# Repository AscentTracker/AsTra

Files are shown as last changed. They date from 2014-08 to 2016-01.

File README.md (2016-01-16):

AsTra
=====

Ascent Tracker "AsTra" is an Arduino-based altitude data logger for
(indoor)climbing.

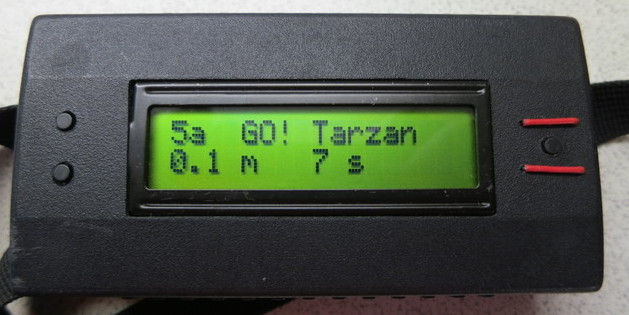
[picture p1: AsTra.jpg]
AsTra picture
 

AsTra is a smallish (12x6x2.5 cm, 200 g) wearable device to record
altitude (based on barometric pressure) four times a second to an
SD card. For convenience also time, name of the climber and grade of
the route are selectable and stored with every ascent. The data are
processed with a Perl program to yield daily ascent curves (with
[dygraphs](http://dygraphs.com/)) for every climber.

The [demo graph for Tarzan](http://www.helsinki.fi/~syrjanen/AsTra/Tarzan/2014-05-27.html)
displays each ascent as a curve, height versus time. You can select
which ascents are visible, zoom in with mouse etc. Monthy and yearly
[statistics](http://www.helsinki.fi/~syrjanen/AsTra/Tarzan/Stats.html) are calculated for every climber.

Check these directories for more information on design, inspiration and
building the hardware and software:

- [hw](hw): AsTra hardware and Arduino software
- [tools](tools): Linux software and tools for graphing AsTra data

Pictures, demo video and some notes on building AsTra can be found
in [AsTra image library](http://pars.kuvat.fi/kuvat/AsTra/?pw=AsTra)

&copy; Seppo Syrjänen 2014, 2016

*Contact: ascend dot tracker at gmail dot com*

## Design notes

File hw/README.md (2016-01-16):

AsTra
=====

I wanted log my indoor climbing ascents with some automatic tracking
device to map altitude versus time. Measuring altitude could be done
actively with ultrasound or optical ranging but modern barometric
pressure sensors could do that passively and without calibration,
especially when only relative altitudes are required.

I was amazed by the
[videos](http://www.varesano.net/blog/fabio/ms5611-01ba-arduino-library-first-developments-results)
by Fabio Varesano about barometric pressure sensor MS5611-01BA01. A
resolution of a 50 cm would have been enough for logging climbing
routes but sensitivity of just 10 centimeters was more than I could
have hoped for. Individual altitude readouts from the sensor are noisy,
but averaging and filtering saves the day.

AsTra is also inspired by these projecs and tutorials:

* [FreeIMU](http://www.varesano.net/projects/hardware/FreeIMU) has the current library for MS5611
* [Altduino](http://www.altduino.de/) altitude logger for model rockets
* [openxvario](https://code.google.com/p/openxvario/) for RC planes, especially for **Kalman filtering** code
* [Arduino DIY SD Card Logging Shield](http://www.instructables.com/id/Arduino-DIY-SD-Card-Logging-Shield/) for cheap LC Studio SD card breakout
* [SD Card info in arduino-info](http://arduino-info.wikispaces.com/SD-Cards)
* [Why not to use 9 V batteries](http://cybergibbons.com/uncategorized/arduino-misconceptions-6-a-9v-battery-is-a-good-power-source/)
* [Resistor ladder](http://tronixstuff.com/2011/01/11/tutorial-using-analog-input-for-multiple-buttons/) to read multiple buttons via one analog input
* [Analog debounce](https://github.com/MatCat/AnalogDebounce) library to simpilify reading the buttons
* [Optimizing RAM usage](http://learn.adafruit.com/memories-of-an-arduino/optimizing-sram)

Parts list
----------

- Arduino Mini Pro 5V
- SCG MS5611 breakout
- Sparkfun Logic Level Converter
- Adafruit RTC module
- Sparkfun NCP1402-5V Step-Up Breakout
- 1117T-3.3V regulator + capacitors
- Sparkfun MicroSD breakout
- 2 x 16 LCD display
- buttons, resistors
- project box

Cost ~ 100 €, build time ~ 100 hours (includes lots of hw and sw prototyping & documentation) ;-)

Building the hardware
---------------------

I got my MS5611 breakout from
[CSG](http://www.csgshop.com/category.php?id_category=10). It arrived
with no documentation so I just had to guess with help of a similar
product by
[Drotek](http://www.drotek.fr/shop/en/home/44-ms5611-pressure-barometric-board.html)
on how to enable I2C mode and select the device address by soldering
**two** jumper pads.

Cheap SD card module from LC Studio was too big for my enclosure so I had to
use a MicroSD version from Sparkfun. That had the nice bonus of
eliminating the need for a 4050 level converter.

[Fritzing](http://fritzing.org/home/) [breadboard
view](AsTra-V0.44_bb.png) was a nice way
to plan and document(!) wirings on a proto board. Export to a PNG and
flip it over to give view from the solder side. Fritzing [schematic
view](AsTra-V0.44_schem.png) was
used in documenting the actual circuit design. Download
[AsTra-V0.44.fzz](AsTra-V0.44.fzz) for
complete Fritzing project.

I used [Inkscape](http://www.inkscape.org/en/) to draw "parts" for the
connectors and to rescale some (inch-measured?) Sparkfun
[parts](https://github.com/adafruit/Fritzing-Library/blob/master/parts/2.2%20TFT%20with%20MicroSD%20Breakout.fzpz).

I happened to select a box that was just big enough for all stuff
needed. My hardest build this far, using only hand tools.

Software 
--------

Version: [AsTra_V1.06](AsTra_V1_06.ino)

Program (event) logic is implemented as a Finite State Machine (FSM, see
graph [AsTra-FSM1-1-1.png](AsTra-FSM1-1-1.png)).

Sensor readings are cleaned with Kalman digital filtering. Also a
32-slot moving average is calculated for debugging. See [DATA.md](DATA.md) for
all fields. 

Starting and stopping the ascent tracking automatically (as indicated
in FSM and AUTOSTART macro in code) was more trouble than it was
worth. One button push before and two after ascent is mostly not too
much to remember. 

Arduino memory size limits are always a problem: some recent change in
Arduino IDE (Linux versions) bloated the binary over maximun size so I
had to disable all serial debugging output. Maybe I need a debugging
version with partial functionality?

MS5611 library returning NULL for a float on invalid data got me in a
big way. Note that
[MS561101BA_altitude.pde](https://github.com/PaulStoffregen/FreeIMU/blob/master/libraries/MS561101BA/examples/MS561101BA_altitude/MS561101BA_altitude.pde)
does NOT check for NULL return values as
[MS561101BA_simple.pde](https://github.com/PaulStoffregen/FreeIMU/blob/master/libraries/MS561101BA/examples/MS561101BA_simple/MS561101BA_simple.pde)
does. Those NULL values messed up the Kalman filtering code and
shortcircuited simple float calculation (foo - NULL = 0.0). Note to
self: always check return values and read interface descriptions.

Climbing grades are according to French (indoor) system: ?, 4, 4+, 5a,
5a+, 5b, 5b+, 5c, 5c+, 6a, 6a+,... Modify gradenum2name() to suit your
needs.

Sensor initialization and setup code is inside loop() because
replicating them in setup() would bloat the binary. Sorry for the
inconvenience.

Static variables are used in openLog() to eliminate the need of scanning
the SD card for the next availabe filename while the power is still on.

Device is powered off after 10 minutes on inactivity. This drops the
current consumption from 21 mA to 7 mA so this is mostly an
excercise in power saving techniques.

See [USER-GUIDE.md](USER-GUIDE.md) for how the device is actually used.

Enhancements and alternatives
-----------------------------

Altitude readings tend to drift even when stationary. Longer (in time)
routes tend to end couple of meters higher than started. Possible
causes include temperature at different altitudes, wind and changes in
air conditioning affecting the local barometric pressure. CSV data
have altitude values calculated based on starting and current
temperature (see [DATA.md](DATA.md)) but I have not managed to find any
explanation for the drift.

One might use a second stationary unit for reference like in
differential GPS :-) On the other hand, the device is accurate enough
for my current needs where a resolution of 0.5 meters would suffice.

Alternative sw/hw designs:

* use TinyFAT as SD library (partition card for smaller capacity)
* replace AnalogDebounce with a smaller implementation
* replace rest of printfs with smaller code
* use I2C EEPROM chip for storage, build data download functionality
* add a BlueTooth connection to PC/smartphone app
* use LiPo as power source
* PCB

**See more notes on building in [image captions](http://pars.kuvat.fi/kuvat/AsTra/)**

Be sure to check [Climbit](http://www.instructables.com/id/Climbit/)
for a more modern choice of components. I started AsTra when e.g. Trinket
and OLED displays were not readily available.

&copy; Seppo Syrjänen 2014,2016

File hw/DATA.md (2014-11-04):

AsTra Data
----------

Each ascent is recorded to a file on SD card (poweroff before
removing card). Filenames are in format of YYMMDDAA.CSV
where YY is year (with two digits, sorry Y2K), MM is month, DD is day
and AA goes from AA to ZZ (so there is room for 625 ascents for each day).

First line has metadata in JSON-format, rest of the lines have
altitude etc data for the ascent in CSV format.
Line "#FAILED" indicates an ascent that has been marked as failed by the Set-button.

AsTra does not record location information. Location is added to
JSON metadata with _setloc_ utility. It can also be specified on command line
to _adastra_.

CSV fields are as follows (mostly used for debugging):

- milliseconds from start
- raw altitude from the sensor (based on starting temperature), in meters
- moving average of altitude
- kalman filtered altitude: only this is used by adastra
- power supply voltage
- altitude based on current temperature
- current temperature, degrees of C

AsTra V 1.* hardware stores four (4) records every second, _adastra_
uses every other of them.

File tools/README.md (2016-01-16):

AsTra Data Reporting
=================

You can plot AsTra CSV files in any way you want, see [DATA.md](DATA.md) for
field information. These Linux flavored
tools produce HTML+CSV files for [dygraphs](http://dygraphs.com/) visualization library and
Apache flavored www server. Porting to Windows and IOS would not be
too hard.

Software needed:

- rsync to smartly move files, use cp if not available
- Perl

*Tools provided*:

- _getnew_: shell program to fetch new files from SD card, runs _adastra_
- _adastra_: Perl program to process CSV files to logs and WWW reports
- _stats_: Perl program to calculate montly and yearly statistics for every climber
- _publish_: shell program for publishing the results, runs stats first
- _setloc_: Perl program to set JSON location field in CSV files

Install
-------

* edit mount point to _getnew_
* edit WWW charset to _adastra_
* edit publish location to _publish_ (optional)
* chmod a+x getnew adastra publish setloc

Quick usage
-----------

* insert SD card
* ./getnew Location (automatically fetches new files and runs adastra with them)
* ./publish (if you want to publish them to a www server)

You can view the reports with a modern browser in directory [www](www).

You can set location info to CSV files like this

 ./setloc -loc Location data/140606*.CSV

and make reports from those files

 ./adastra -v data/140606*.CSV

You can override location with adastra option -loc

&copy; Seppo Syrjänen 2014,2016

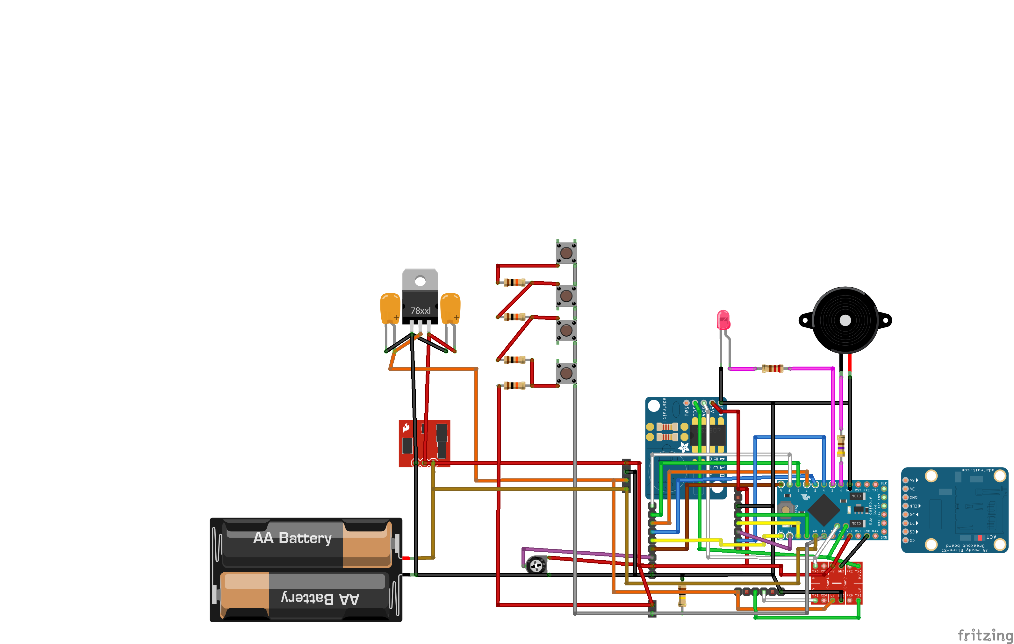
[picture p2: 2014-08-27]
hw/AsTra-V0.44_bb.png

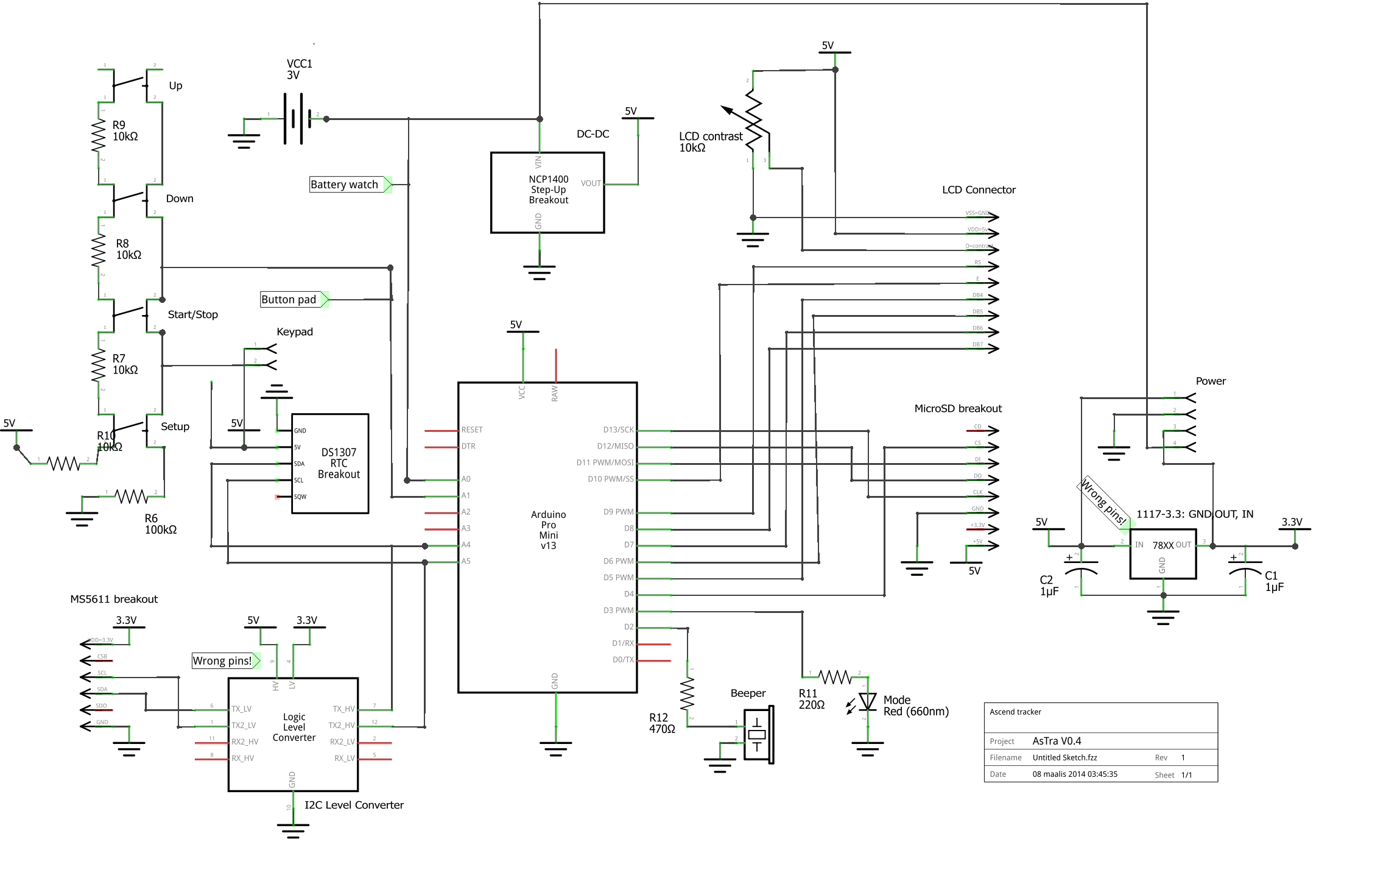
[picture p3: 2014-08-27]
hw/AsTra-V0.44_schem.png

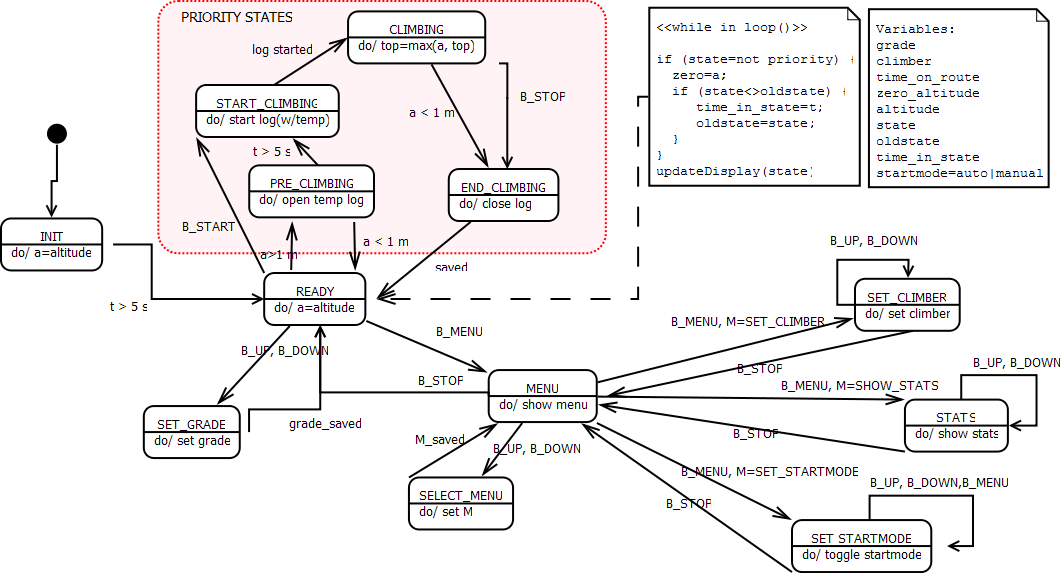
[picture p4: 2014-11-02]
hw/AsTra-FSM1-1-1.png

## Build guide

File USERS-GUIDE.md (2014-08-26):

AsTra Users Guide
=================

Basics
------

- Turn on with power switch, wait 10 seconds for startup/calibration
- Silent mode (no beeps): press any button at poweron 
 or set "b 0" in settings.txt on SD card
- Select grade with Up/Down buttons (?,4,4+,5a,5a+,...9c+)
- Select climber with Set-button (on left edge next to power switch)
- Start climbing with Go-button: clock starts ticking, three beeps
played and GO! displayed
- End climbing with Go-button (finished) or Set-button (failed to
 finish). Totals (altitude and seconds) are displayed until Go is pushed.
- Auto poweroff after 10 minutes of idle (set "i 0" in settings.txt to disable)

Display
-------

The two row LCD displays the following information.

At Power on:
 AsTra version information and battery voltage.

Idle: 

 Left | Middle | Right
 ---- | -------| -----
 Route grade | Alt zero level (blinking square) | Climber name
 Altitude| | Time
 
Climbing:

 Left | Middle | Right
 ---- | -------| -----
 Route grade | GO! | Climber name
 Altitude | |  Elapsed time
 
Stop:

 Left | Middle | Right
 ---- | -------| -----
 Route grade | END | Climber name
 Max altitude | | Time to max alt

Data
----

Each ascent is recorded to a file on SD card (poweroff before
removing card). Filenames are in format of 

 YYMMDDab.CSV

where YY is year (with two digits, sorry Y2K), MM is month, DD is day
and ab goes from AA to ZZ (there is room for 625 ascents for each day).

First line has metadata in JSON-format, rest of the lines have
altitude etc data for the ascent in CSV format.
Line "#FAILED" indicates an ascent that has been marked as failed by the Set-button.

AsTra does not record location information. Location is added to
JSON metadata with _setloc_ utility. It can be specified on command line
also to _adastra_.

CSV fields are as follows (mostly used for debugging):

- milliseconds from start
- raw altitude from the sensor (based on starting temperature)
- moving average of altitude
- kalman filtered altitude: only this is used by adastra
- power supply voltage
- altitude based on current temperature
- current temperature

AsTra stores four (4) records every second, _adastra_ displays two of
them.

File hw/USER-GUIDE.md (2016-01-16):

AsTra Users Guide V1.06
=======================

Basics
------

- Turn on with power switch, wait 10 seconds for startup/calibration
- Silent mode (no beeps): press any button at poweron 
 or set "b 0" in settings.txt on SD card
- Select grade with Up/Down buttons (?,4,4+,5a,5a+,...9c+)
- Select climber with Set-button (on left edge next to power switch)
  Running statistis (since poweron) for each climber are displayed.
  Press Go to select climber.
- Start climbing with Go-button: clock starts ticking, three beeps
  played and GO! displayed
- End climbing with Go-button (finished) or Set-button (failed to
  finish). Totals (altitude and seconds) and END are displayed until Go is pushed.
- Auto poweroff after 10 minutes of idle (set "i 0" in settings.txt to disable)
- If battery voltage drops below 2.0 V a warning and voltage reading are
  displayded until power is recycled. Exact safe lowest voltage level
  is unknown.
- set "d 1" in settings.txt to enable Daylight Savings Time (no need
  to adjust RTC)

Display
-------

The two row LCD displays the following information.

**At Power on:**
 AsTra version information and battery voltage.

**Idle:** 

 Left | Middle | Right
 ---- | -------| -----
 Route grade | Alt zero level (blinking square) | Climber name
 Altitude| | Time
 
**Climbing:**

 Left | Middle | Right
 ---- | -------| -----
 Route grade | GO! | Climber name
 Altitude | |  Elapsed time
 
**Select climber:**

 Left | Middle | Right
 ---- | -------| -----
 Total ascents | | Climber name
 Total meters | | Total time

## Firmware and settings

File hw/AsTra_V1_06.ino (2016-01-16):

/*

Arduino Mini Pro 5V ATmega328

FIX
-i 10 setting for idle poweroff
-b 0 setting for mute

22.11.2015
 -d 1 to set daylight savings time

23.5.2015
 -stats
 -shorten beeps and init delay

26.1.2015
 -fixed: idle poweroff entered when ascent longer than 10 minutes was marked as failed (introduced B_NONE) 

27.10.2014

+9c+ grade?

20.8.2014

 TODO:
 -smaller analogDebounce
 -smaller getSettings
 -use tinyFAT, writeLn -> write (no long string buffer)?

Version history:

0.24
 -log current temperature and temp_altitude based on it (long ascents tend to end higher than they started; why?) 

0.23
 -auto shutoff after idle

1.01
 -voltage display at startup, grade 4+

1.05
 -show daily stats at climber selection

*/


// Poweroff if idle after 10 minutes
#include <avr/sleep.h>


#include <ctype.h>
#include <SD.h>

#define SHOWFREEMEM 0
#define HWLCD 1
#define HWRTC 1
#define TEMPDEBUG 0

byte HWSD=1;

#define buttonPin A1
#define piezoPin 2
#define chipSelect 4


#include <Wire.h>
#include <MS561101BA.h>
#if HWRTC
#include <RTClib.h>
#endif

#if HWLCD
#include <LiquidCrystal.h>

// initialize the library with the numbers of the interface pins
// LiquidCrystal LCD(RS, Enable, D4, D5, D6, D7)

LiquidCrystal LCD(9, 10, 5, 6, 7, 8);

#endif

#include <AnalogDebounce.h>
  AnalogDebounce Buttons(buttonPin,ButtonPush);  // Analog Input 0, 

#define B_UP 2
#define B_DOWN 3
#define B_START 1
#define B_MENU 4
#define B_NONE 5


#define S_IDLE 1
#define S_PRECLIMBING 2
#define S_CLIMBING 3
#define S_POSTCLIMBING 4
#define S_SHOW 5
#define S_SELECTCLIMBER 6


// ?,4,4+,5a,5a+,...9c+
#define MAXGRADE 32

RTC_DS1307 RTC; // define the Real Time Clock object
DateTime now;


#define MOVAVG_SIZE 32

MS561101BA baro = MS561101BA();

float movavg_buff[MOVAVG_SIZE];
int movavg_i=0;

const float sea_press = 1013.25;
float press, temperature;

// Timestamps for time and date
char stime[9]; // add space for string terminators! 
char sdate[11];


// the logging file
File logfile;


// Filename template
char filename[] = "YYMMDD00.CSV";


float avg_altitude;
float raw_altitude;
float zero;
float lastaltitude;
// float rate;
float kalman_altitude=0.0;
float maxalt=0.0;

uint32_t mnow=0;
uint32_t lastprint=0;
uint32_t lastsync=0;
uint32_t starttime=0;
uint32_t endtime=0;
uint32_t start_stop_autotimer=0;
uint32_t zerotime=0;
uint32_t INTERVAL=250;
// auto poweroff after 10 minutes with no button activity
uint32_t lastbuttontime=0;
#define IDLEPOWEROFF 600000 

char str[6];
byte grade=3; // start with 5a
byte beep=2; // 0=silent, 1=startup & error, 2=all
byte mute=0; // set to 1 if button pressed at boot
byte failed=0; // failed to ascend to the top
byte autostart=1; // enable autostart/stop
byte button=0;
byte initloop=0;
byte state=S_IDLE;
byte displayvolts=0;
byte dst=0;

byte numclimbers=0;
char **climbername=NULL;
byte climber=0;

struct stat_r
{
  byte ascents;
  float meters;
  int seconds;
};

typedef struct stat_r Stat;

Stat *stats=NULL;


/***************************************************************************************/
/* sensitivity / data filtering / n filter parameters                             */
/* The Kalman Filter is being used to remove noise from the MS5611 sensor data. It can */
/* be adjusted by changing the value Q (process Noise) and R (Sensor Noise).           */
/* Best pactise is to only change R, as both parametrers influence each other.         */
/* (less Q requires more R to compensate and vica versa)                               */
/***************************************************************************************/
#define KALMAN_Q 0.05 // 0.05 do not tamper with this value unless you are looking for adventure ;-)
#define KALMAN_R 80  // default:300   change this value if you want to adjust the default sensitivity!
                      // this will only be used if PIN_PPM is NOT defined
                      //  50 = fast but lot of errors (good for sensor testing...but quite a lot of noise)
                      // 300 = medium speed and less false indications (nice medium setting with 
                      //       a silence window (indoor)of -0.2 to +0.2)
                      // 1000 = conservative setting ;-)
                      // 500 = still useable maybe for a slow flyer?
                      // 1000 and q=0.001 is it moving at all?? in stable airpressure you can measure 
                      //      the height of your furniture with this setting. but do not use it for flying ;-)
                      // .. everything inbetween in relation to these values.

float kalman_q= KALMAN_Q; //process noise covariance
float kalman_r= KALMAN_R; //measurement noise covariance

// Kalman filter variables/parameters
float p=100; //estimation error covariance
float k=0; //kalman gain

// <<<<<<<<<<<<<<<<<<<<<<<<<<<<<<<<<<<<<<<<<<<<<<<

#define S(a) Serial.print(a);
// As of IDE 1.1 no more code space for serial debugging, pity
#define S(a) ;
#define L(a) S(a); logfile.print(a);


#include <avr/pgmspace.h>

// http://forum.arduino.cc/index.php?topic=110307.0

#define FS(x) (__FlashStringHelper*)(x)
#define pm PROGMEM

const char MyName[]        pm ={"AsTra V: "};
const char Version[]       pm ={"1.06"};
const char Battery[]       pm ={"Battery: "};
const char Spaces3[]       pm ={"   "};
const char Spaces4[]       pm ={"    "};
const char SpaceMSpace[]   pm ={" m "};
const char SpaceS[]        pm ={" s"};
const char sError[]        pm ={"Error: "};
const char mallocFailed[]  pm ={"malloc failed"};
const char autoPoweroff[]  pm ={"Idle -> Poweroff"};

// LCD positions Row 1 and 2, Left, Middle and Right columns
#define LCD_R1L 0,0
#define LCD_R1M 4,0
#define LCD_R1R 8,0
#define LCD_R2L 0,1
#define LCD_R2R 8,1

#define FR1 4000
#define BATTERYWARN 2.0 // still to be verified

float supplyvoltage=0.0;

void getVoltage () {        
   supplyvoltage = analogRead(A0);
   delay(10);
   supplyvoltage = analogRead(A0)*(5.0 / 1023);
}


// -------------------------------------------

/*

void statdump(void) {

    Serial.println(stats[climber].ascents);
    Serial.println(stats[climber].meters);
    Serial.println(stats[climber].seconds);
    
}
*/

// -------------------------------------------

void setup() {
  Serial.begin(9600);

  // mute if a button pressed while boot
  if (analogRead(buttonPin)>10) {
    mute=1;
    beep=0;    
  };

  pinMode(piezoPin,OUTPUT);

  // say hello
  buzz(piezoPin, 200, 100, 0);
    
 
  // Initialize the SD card  
  if (HWSD) {
    if (!SD.begin(chipSelect)) {
      HWSD=0;
    } else {
      getSettings();
    };
  };

  if (mute) beep=0;

  // No climbers in settings file, let Tarzan loose!
  if (numclimbers==0) {
    numclimbers=1;
    climbername = (char **)malloc (sizeof (char *) * numclimbers);
    if (!climbername) {
      error(mallocFailed);
    }
    climbername[0]=strdup("Tarzan");  
  }; 
  
  // Start with first climber  
  climber=0;  

  // Initialize statistics array
  stats = (Stat *)malloc (sizeof (Stat) * numclimbers);
  if (!stats) {
      error(mallocFailed);
  }

  for (byte i=0; i<numclimbers; i++) {
    stats[i].ascents=0;
    stats[i].meters=0.0;
    stats[i].seconds=0;
  };  

  // get power supply voltage
  getVoltage();

#if HWLCD
  // set up the LCD's number of columns and rows: 
  LCD.begin(16, 2);
  
  // Print a message to the LCD.  
  LCD.setCursor(LCD_R1L);
  LCD.print(FS(MyName));
  // LCD.setCursor(LCD_R1R);
  // LCD.print(F(" "));
  LCD.print(FS(Version));
  if (dst>0) { LCD.print(F(" *"));};
  // LCD.setCursor(LCD_R2R);
  // LCD.print(F(__TIME__));
  LCD.setCursor(LCD_R2L);
  LCD.print(FS(Battery));
  LCD.print(supplyvoltage);
  LCD.print(F(" V "));
#endif

  // Connect to RTC
  Wire.begin();
  
  if (!RTC.begin()) {
    error("RTC");
  }
 
  // Init MS5611 barometric sensor
  baro.init(MS561101BA_ADDR_CSB_LOW); 
  delay(100);
 
} // end of setup


float temp_altitude;
float temp0;

// =====================================================================

void loop() {

  // check buttons first for best responsiveness
  Buttons.loopCheck();    

  // Must check for invalid values (NULL)    
  temperature=NULL; 
  while(temperature == NULL) {
    temperature = baro.getTemperature(MS561101BA_OSR_4096);
    // delay(20);
  }
  
  press=NULL;
  while (press == NULL) {
    press = baro.getPressure(MS561101BA_OSR_4096);
    // delay(20);
  };
  
  raw_altitude=getAltitude(press, temp0);

  // Update moving average
  pushAvg(press);
  press = getAvg(movavg_buff, MOVAVG_SIZE);
  avg_altitude=getAltitude(press, temp0);
  temp_altitude=getAltitude(press, temperature);
    
  // Update the prediction value
  p = p + kalman_q;

  // Update based on measurement
  k = p / (p + kalman_r);
  kalman_altitude = kalman_altitude + k * (raw_altitude - kalman_altitude);
  p = (1 - k) * p;

  // Get power supply voltage
  getVoltage();

// ============================================
 // Sensor init & avg buffer fillup delay 
// ============================================
    
 if (initloop < MOVAVG_SIZE) {
   temp0=temperature;
   initloop++;
   if (button) {
    mute=1;
    beep=0;
   }
   /* 
   LCD.setCursor(LCD_R2L);
   LCD.print(FS(Battery));
   LCD.print(supplyvoltage);
   LCD.print(F(" V "));
   */
   // LCD.write(255);
   delay(40);
   return;
 } else if (initloop == MOVAVG_SIZE) { // end of init looping
   initloop++;
    
#if HWLCD
    LCD.clear();
    LCD.setCursor(LCD_R1L);
    LCD.print(gradenum2name(grade,str));
    LCD.setCursor(LCD_R1R);
    LCD.print(climbername[climber]);
#endif

   return;
 };


    // millis() now  
    mnow=millis();

    // Fetch the time
    now = RTC.now();

    // Timestamps, lazy DST handling
    sprintf(stime, "%02d:%02d:%02d", now.hour()-dst, now.minute(), now.second());
    sprintf(sdate, "%d-%02d-%02d",   now.year(), now.month(),  now.day());
 
// ============================================
//   BUTTONS
// ============================================

 switch (button) {  
   case B_START:
     buzz(piezoPin, FR1, 100, 100);
     switch (state) {
       case S_IDLE:     setZero(); state=S_PRECLIMBING; break;
       case S_CLIMBING: state=S_POSTCLIMBING; break;
       case S_SHOW:     setZero(); state=S_IDLE; break;
       case S_SELECTCLIMBER:    setZero(); state=S_IDLE; 
#if HWLCD
            LCD.setCursor(LCD_R1L);
            LCD.print(gradenum2name(grade,str));
            LCD.print(FS(Spaces4));
#endif         
       break;
     };
     break;
   case B_MENU: // mark ascent aborted
     switch (state) {
       case S_CLIMBING: failed=true; button=B_NONE; state=S_POSTCLIMBING; break;
       case S_IDLE: button=B_NONE; state=S_SELECTCLIMBER; break;
       case S_SELECTCLIMBER:
             button=B_NONE;
             climber++;
             if (climber>=numclimbers) climber=0;
#if HWLCD
            LCD.setCursor(LCD_R1R);
            LCD.print(climbername[climber]);
            LCD.print(FS(Spaces4));
#endif         
            break;
     };
 };
 
if (state==S_IDLE) {
 switch (button) {     
   case B_UP:
     if (grade<MAXGRADE) grade++;
#if HWLCD
    LCD.setCursor(LCD_R1L);
    LCD.print(gradenum2name(grade,str));
    LCD.print(FS(Spaces4));
#endif    
     break;

   case B_DOWN:
     if (grade>0) grade--;
#if HWLCD
    LCD.setCursor(LCD_R1L);
    LCD.print(gradenum2name(grade,str));
    LCD.print(FS(Spaces4));
#endif    
     break;

/*
   case B_MENU:
     climber++;
     if (climber>=numclimbers) climber=0;
#if HWLCD
    LCD.setCursor(LCD_R1R);
    LCD.print(climbername[climber]);
    LCD.print(FS(Spaces4));
#endif         
     break;
*/ 

 }; // end switch button
}; 

// -----------------------------------------------

switch (state) {
  case S_IDLE:
  
#if AUTOSTART  
    // start when above X meters for y seconds
    if (kalman_altitude-zero > 0.7) {
      if (start_stop_autotimer==0) {
        start_stop_autotimer=mnow;
      } else if (mnow-start_stop_autotimer > 2000) {
        // if (autostart) state=S_PRECLIMBING;
      };
    } else {
      start_stop_autotimer=0;
    };
#endif

   // set zero level when idle and one of these:
   //  -some button is pressed
   //  -10 seconds after boot
   //  -10 seconds after last re-set when after init and not waiting to climb over autostart level
    // if (((start_stop_autotimer==0) && (mnow > 10000)) && (button || (mnow < 10000) || (mnow-zerotime>10000))) {
    if ((button || (mnow < 5000) || 
          ((mnow > 5000)  && (mnow-zerotime>30000) && (start_stop_autotimer==0)))) {
     setZero();
     zerotime=mnow;
    };
    
    if (mnow-lastbuttontime > IDLEPOWEROFF) {
      buzz(piezoPin, 200, 100, 0);

      LCD.clear();
      LCD.setCursor(LCD_R1L);
      LCD.print(FS(autoPoweroff));
  
      set_sleep_mode(SLEEP_MODE_PWR_DOWN);   // sleep mode is set here
      sleep_enable();          // enables the sleep bit in the mcucr register
      sleep_mode();            // here the device is actually put to sleep!!
    };
    break;
    
  case S_CLIMBING:
#if AUTOSTART
    // stop when under X meters for z seconds
    if (kalman_altitude-zero < 1.0) {
      if (start_stop_autotimer==0) {
        start_stop_autotimer=mnow;
      } else if (mnow-start_stop_autotimer > 120000) {
        if (autostart) state=S_POSTCLIMBING;
      };
    } else {
      start_stop_autotimer=0;
    };    
#endif    
  break;
  
  case S_PRECLIMBING: // start climbing
    if (HWSD) {
      openLog(now.year(), now.month(), now.day());
      if (! logfile) {
        error("Create file");
      }
     };

    L(F("{ "));
    L(F("\"version\":\""));
    L(F("1.2"));
    L(F("\", \"file\":\""));
    L(filename);
    L(F("\", \"date\":\""));
    L(sdate);
    L(F("\", \"time\":\""));
    L(stime);
    L(F("\", \"epoch\":\""));
    L(now.unixtime());
    L(F("\", \"climber\":\""));
    L(climbername[climber]);
    L(F("\", \"grade\":\""));
    L(gradenum2name(grade,str));
    L(F("\", \"voltage\":\""));
    L(supplyvoltage);   
    L(F("\", \"zero\":\""));
    L(zero);
    L(F("\", \"temp\":\""));
    L(temp0);
    L(F("\" }\n"));
  
    starttime=endtime=lastsync=mnow;
    failed=false;
    state=S_CLIMBING;
    
     buzz(piezoPin, FR1, 50, 20);
     buzz(piezoPin, FR1, 50, 20);
     buzz(piezoPin, FR1, 50, 20);
    
#if HWLCD
    LCD.clear();
    LCD.setCursor(LCD_R1L);
    LCD.print(gradenum2name(grade,str));
    LCD.setCursor(LCD_R1R);
    LCD.print(climbername[climber]);
#endif
  break;
  
 case S_POSTCLIMBING:
    if (HWSD) {
       if (failed) {
         L("#FAILED\n");
       };
       logfile.flush();
       logfile.close();
    };
    buzz(piezoPin, FR1, 500, 50);
    endtime=mnow;

     if (!failed) {
      // Update per climber statistics for this session
        stats[climber].ascents++;
        stats[climber].meters+=maxalt-zero;
        stats[climber].seconds+=(endtime-starttime)/1000;
    }

    // statdump();
    
    state=S_SHOW;
    break;
  
}; // switch state

  if (button) {
    lastbuttontime=mnow;
    button=0; // debounce does not work? :)
  };

// ============================================
//   DISPLAY
// ============================================

  // update display only every INTERVAL  
  if (((mnow-lastprint)>INTERVAL)) {

#if TEMPDEBUG
    temp0_altitude=getAltitude(press, temp0);
    S(raw_altitude-zero);
    S(',');
    S(temp0_altitude-zero);
    S(',');
    S(avg_altitude-zero);
    S(',');
    S(kalman_altitude-zero);
    S('\n');
#endif    


    // Update display
#if HWLCD     
    if (state == S_CLIMBING) { // show altitude and elapsed seconds
      LCD.setCursor(LCD_R1M);
      if (HWSD) {
        LCD.print(F("GO!"));
      } else {
        LCD.print(F("!SD"));
      };
      LCD.setCursor(LCD_R2L);    
      LCD.print(kalman_altitude-zero,1);
      LCD.print(FS(SpaceMSpace));
      LCD.print(FS(Spaces4));
      // LCD.print(F("    "));
      LCD.setCursor(LCD_R2R);      
      LCD.print((mnow-starttime)/1000);
      LCD.print(FS(SpaceS));
      
    } else if (state == S_SHOW) { // show results
      LCD.setCursor(LCD_R1M);
      LCD.print(F("END"));
      LCD.setCursor(LCD_R2L);
      LCD.print(maxalt-zero,1);
      LCD.print(FS(SpaceMSpace));
      LCD.print(FS(Spaces4));
      LCD.setCursor(LCD_R2R);      
      LCD.print((endtime-starttime)/1000);

    } else if (state == S_SELECTCLIMBER) { // show climber statistics
      LCD.setCursor(LCD_R1L);
      LCD.write(0xf6); // sigma
      LCD.print(F(" "));
      // LCD.print(F("Total "));
      LCD.print(stats[climber].ascents);
      LCD.print(F("  "));
      LCD.setCursor(LCD_R2L);
      LCD.print(stats[climber].meters,1);
      // LCD.print(FS(Spaces4));
      LCD.print(FS(SpaceMSpace));
      LCD.setCursor(LCD_R2R);      
      LCD.print(stats[climber].seconds);
      LCD.print(FS(SpaceS));
      LCD.print(FS(Spaces4));
      LCD.print(F("  "));

    } else { // state==IDLE show battery and time
      LCD.setCursor(LCD_R1M);
      LCD.print(FS(Spaces3));
      LCD.setCursor(LCD_R2L);
      if (supplyvoltage < BATTERYWARN) { // battery warning
        LCD.print('!');
        LCD.print(' ');
        displayvolts=1;
      };
      if (displayvolts) {
       LCD.print(supplyvoltage,1);
       LCD.print('V');
       LCD.print(' ');
      } else {
       LCD.print(kalman_altitude-zero,1);
       LCD.print(F(" m "));
      };
      LCD.setCursor(LCD_R2R);      
      LCD.print(stime);
    };
#endif 

// ============================================
// UPDATE LOG DATA
// ============================================

  // Update log and/or serial console
  if (state==S_CLIMBING) {
    L(mnow-starttime);
    L(',');
    L(raw_altitude-zero);
    L(',');
    L(avg_altitude-zero);
    L(',');
    L(kalman_altitude-zero);
    L(',');
    L(supplyvoltage);   
    L(',');
    L(temp_altitude-zero);
    L(',');
    L(temperature);
    L('\n');

    // sync every 15 seconds
    if (mnow-lastsync > 15000) {
      logfile.flush();
      lastsync=mnow;
 /*      
#if HWLCD
      LCD.setCursor(LCD_R2L);
      LCD.print("                ");
      LCD.setCursor(LCD_R1L);
      LCD.print(supplyvoltage);
      LCD.setCursor(5,1);
      LCD.print("SYNC ");
      LCD.print(maxalt-zero);
      delay(1000);
      LCD.setCursor(LCD_R1L);
      LCD.print("                ");
      // LCD.clear();
  #endif
 */  
    }; // sync
  }; // climbing
    
   lastprint=mnow;
   // lastaltitude=avg_altitude;
   maxalt=max(maxalt,kalman_altitude);
    
  };
  delay(20);
}


// ============================================
// -----------------------------------------------------


float getAltitude(float press, float temp) {
  //return (1.0f - pow(press/101325.0f, 0.190295f)) * 4433000.0f;
  return ((pow((sea_press / press), 1/5.257) - 1.0) * (temp + 273.15)) / 0.0065;
}

void pushAvg(float val) {
  movavg_buff[movavg_i] = val;
  movavg_i = (movavg_i + 1) % MOVAVG_SIZE;
}

float getAvg(float * buff, int size) {
  float sum = 0.0;
  for(int i=0; i<size; i++) {
    sum += buff[i];
  }
  return sum / size;
}

/*
*
* gradenum: 0=?, 1=4, 2=5a, 3=5a+, ...
* *buff=return value
*
*/

char *gradenum2name(byte gradenum, char *buff) {
   
    char append[2];
  
    if (gradenum<1) {
       strcpy(buff,"?");
       return buff;
    } 
    gradenum--;
    if (gradenum<1) {
       strcpy(buff,"4");
       return buff;
    } 
    gradenum--;
    if (gradenum<1) {
       strcpy(buff,"4+");
       return buff;
    } 
    gradenum--;
   
    byte grade=gradenum/6;
    byte subgrade=gradenum%6;
    byte letter=subgrade/2;
    byte plus=subgrade%2;
    
    itoa(5+grade,buff,10);
    append[0]=char(97+letter);
    append[1]='\0';
    strcat(buff,append);    
    append[0]=plus?'+':'\0';
    strcat(buff,append);
    
    // sprintf(buff,"%d%c%c",5+grade,char(97+letter),plus?'+':' ');
  
    return buff;
    
};


// --------------------

void error(const char *str)
{

#if HWLCD
  LCD.clear();
  LCD.setCursor(LCD_R1L);
  LCD.print(FS(sError));
  LCD.setCursor(LCD_R2L);
  LCD.print(str);
#endif


  while(1) {
    // buzz(piezoPin, 1200, 200, 2000);
    Serial.print(FS(sError));
    Serial.println(str);
    delay(3000);
  };
}


#if SHOWFREEMEM

// ----- Free RAM http://arduino.cc/playground/Code/AvailableMemory

int freeRam () {
  extern int __heap_start, *__brkval; 
  int v; 
  return (int) &v - (__brkval == 0 ? (int) &__heap_start : (int) __brkval); 
}

#endif


/*

//---------- Floating point value with one rounded decimal

char *f3d1tostr( float f, char *b)
{
  long int t = (f + 0.05) * 100; // round up 1st decimal up, convert to integer: 3.16 -> 321
  t=t/10; // chop off last digit: 32
  // always space for sign
  sprintf(b,"%c%2i.%i",(t < 0 ? '-' : ' '), (int)abs(t/10), (int)abs(t % 10));
  return b;
};

*/


// buzz - smaller implementation of tone()
//  http://www.faludi.com/examples/helpful-arduino-functions/

void buzz(int targetPin, long frequency, long length, int delayafter) {
  // return;
  if (!beep) return;
  // if (targetPin<0) targetPin=-targetPin;
  long delayValue = 1000000/frequency/2;
  // calculate the delay value between transitions
  //// 1 second's worth of microseconds, divided by the frequency,
  //// then split in half since there are two phases to each cycle

  long numCycles = frequency * length/ 1000;
  // calculate the number of cycles for proper timing
  //// multiply frequency, which is really cycles per second, by the
  //// number of seconds to get the total number of cycles to produce
  for (long i=0; i < numCycles; i++){ // for the calculated length of time...
    digitalWrite(targetPin,HIGH); // write the buzzer pin high to push out the diaphram
    delayMicroseconds(delayValue); // wait for the calculated delay value
    digitalWrite(targetPin,LOW); // write the buzzer pin low to pull back the diaphram
    delayMicroseconds(delayValue); // wait again for the calculated delay value
  }

  // SS extension
  if (delayafter) delay(delayafter);
}

// ============================================================================
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

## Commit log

2014-08-20 Arduino scketch V1.01
2014-08-25 loc file ok
    [2014-04-09-Salmisaari.csv, 2014-04-09.csv, 2014-04-12-Salmisaari.csv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]
2014-08-27 mountpoint, default location
2014-08-27 Fritzing files
    [AsTra-V0.44.fzz]
2014-11-03 Demo files for Tarzan
    [140527KA.CSV, 140527KB.CSV, 140527KC.CSV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]
2014-11-03 Tidy up
    [2014-04-09-Salmisaari.csv, 2014-04-12-Salmisaari.csv, 2014-04-13-Salmisaari.csv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]
2015-01-20 new files
    [2015-01-13-Salmisaari.csv, 2015-01-19-Salmisaari.csv]
2016-01-16 Tarzan keeps on climbing
    [2014-04-09-Salmisaari.csv, 2014-04-12-Salmisaari.csv, 2014-04-13-Salmisaari.csv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]
